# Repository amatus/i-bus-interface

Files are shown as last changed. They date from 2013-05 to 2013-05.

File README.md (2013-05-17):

i-bus-interface
===============

This project consists of a Bluetooth adapter that is connected
to the BMW I-Bus and an Android app that talks to the I-Bus
using the adapter.

The main goal of this project is to use the up and down buttons on
the BMW E46 steering wheel to send previous track and next track
commands to the music player on an Android device.

Cadsoft Eagle v6 files for the adapter are in the hardware directory
and Android software is in the android directory.

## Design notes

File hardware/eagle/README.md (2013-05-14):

I-Bus Adapter board
==================

The I-Bus Adapter board is designed to adapt the I-Bus signals to
TTL serial at 9600 baud 8E1. The serial pinout is compatible with
the Virtuabotix [BT2S] Bluetooth Serial Slave device.

I stuffed this board, the BT2S, and the board from a cheap USB phone
car charger into a small project box and connected it to the 3-pin
plug formerly connected to the Sirius satellite radio module in the
trunk of my BMW.

I-Bus Adapter with Power Supply
===============================

This is the same ciruit with the addition of a power supply based on
the MC34063 switching regulator.

Configuring the BT2S
====================

The bluetooth module on the BT2S seems to be a Guangzhou HC
Information Technology Co. [HC-06]. The full command set can be
found in the linked PDF. The module defaults to 9600 8N1 and in order
to change this to 8E1 AT-commands need to be sent to it over the serial
interface. I used an FT232R breakout board and minicom to communicate
with the module. The commands are sent without any pauses between bytes
and are terminated with a pause. They are *not* terminated with a carriage
return or line feed. The easiest way to achieve this is to type the command
out and copy it to the clipboard without a terminating newline, then paste
it into your terminal program. The commands are also not echoed, only the
response will appear in the terminal. The command for changing the parity
to even is `AT+PE`. This does not change the parity for the command
interface, only bluetooth passthrough, so the terminal parity should be left
at none.

Other useful commands:
* `AT+NAMExxxx` will change the name of the device for bluethooth
  discovery to xxxx.
* `AT+PIN0000` will change the pairing code to 0000 (must be 4 digits).
* `AT+PN` will set the parity back to none.

  [bt2s]: https://www.virtuabotix.com/?page_id=3117&productid=609224531705
  [hc-06]: http://www.mcu-turkey.com/wp-content/uploads/2013/01/HC-Serial-Bluetooth-Products-201104.pdf

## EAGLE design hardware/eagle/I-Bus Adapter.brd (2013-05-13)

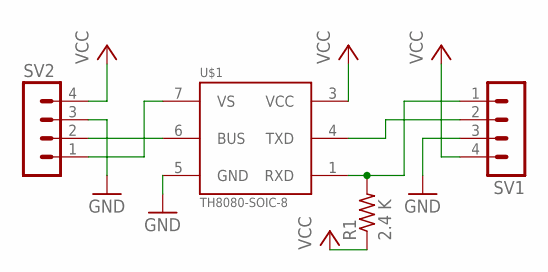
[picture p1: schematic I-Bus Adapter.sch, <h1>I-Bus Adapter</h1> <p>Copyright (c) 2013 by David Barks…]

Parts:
R1: 2.4 K; R1206
SV1, SV2: MA04-1
U$1: TH8080-SOIC-8; SO-8

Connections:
GND: SV1.3, SV2.3, U$1.5 (GND)
unnamed: R1.2, SV1.1, U$1.1 (RXD)
unnamed: SV1.2, U$1.4 (TXD)
unnamed: SV2.2, U$1.6 (BUS)
unnamed: SV2.1, U$1.7 (VS)
VCC: R1.1, SV1.4, SV2.4, U$1.3 (VCC)

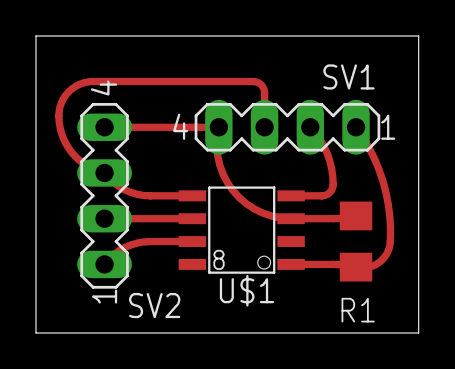
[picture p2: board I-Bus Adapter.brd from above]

Board: 2 copper layers, 21.3 x 16.5 mm, 4 parts (0 on the bottom side), 6 nets.

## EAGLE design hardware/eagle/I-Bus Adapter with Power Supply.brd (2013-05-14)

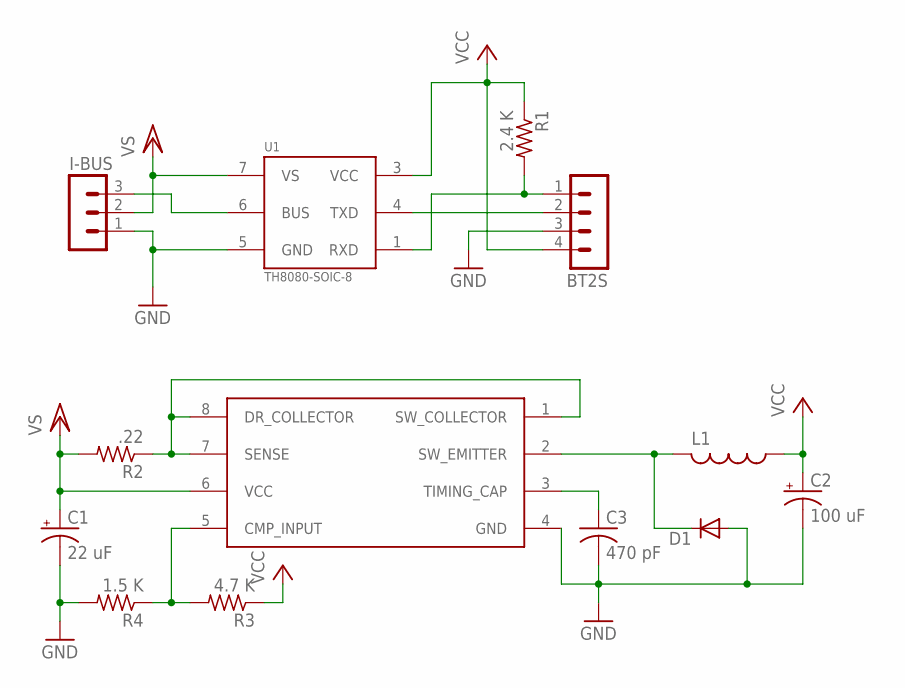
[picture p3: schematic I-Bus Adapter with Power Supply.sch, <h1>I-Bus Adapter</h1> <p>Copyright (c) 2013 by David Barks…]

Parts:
BT2S: MA04-1
C1: 22 uF; E1,8-4
C2: 100 uF; E1,8-4
C3: 470 pF; C0603K
D1: DIODE-D-2.5; D-2.5
I-BUS: MA03-1
L1: L-US0207/2V; 0207/2V
R1: 2.4 K; R1206
R2: .22; R1206
R3: 4.7 K; R2012
R4: 1.5 K; R2012
U1: TH8080-SOIC-8; SO-8
U2: MC34063-SOIC-8; SO-8

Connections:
GND: BT2S.3, C1.-, C2.-, C3.2, D1.A, I-BUS.1, R4.2, U1.5 (GND), U2.4 (GND)
unnamed: BT2S.1, R1.2, U1.1 (RXD)
unnamed: BT2S.2, U1.4 (TXD)
unnamed: R2.1, U2.1 (SW_COLLECTOR), U2.7 (SENSE), U2.8 (DR_COLLECTOR)
unnamed: I-BUS.3, U1.6 (BUS)
unnamed: D1.C, L1.2, U2.2 (SW_EMITTER)
unnamed: R3.2, R4.1, U2.5 (CMP_INPUT)
unnamed: C3.1, U2.3 (TIMING_CAP)
VCC: BT2S.4, C2.+, L1.1, R1.1, R3.1, U1.3 (VCC)
VCC/2: C1.+, I-BUS.2, R2.2, U1.7 (VS), U2.6 (VCC)

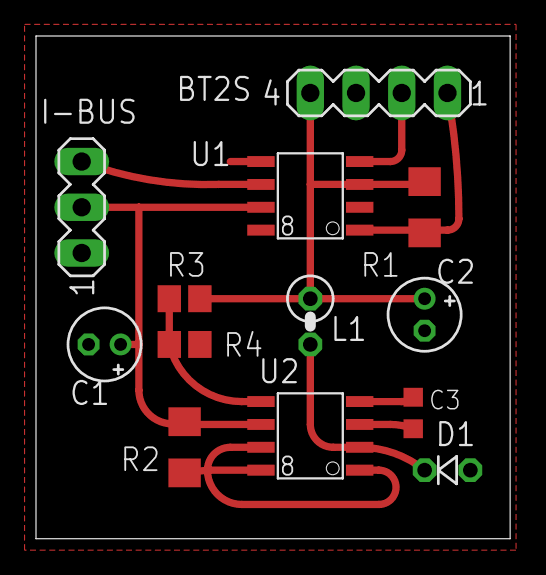
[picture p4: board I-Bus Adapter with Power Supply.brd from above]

Board: 2 copper layers, 26.3 x 27.9 mm, 13 parts (0 on the bottom side), 10 nets.

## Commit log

2013-05-12 I-Bus adapter board design.
    [IBUS_adapter.brd, IBUS_adapter.sch]
2013-05-13 Added CC BY-SA 3.0 license to hardware designs.
    [IBUS_adapter.brd, IBUS_adapter.sch]
2013-05-14 New design with power supply.
    I added a power supply and updated the readme.
    [I-Bus Adapter with Power Supply.brd, I-Bus Adapter with Power Supply.sch, I-Bus Adapter.brd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]
2013-05-23 Added steering wheel button events.
2014-02-17 New design based on the TI CC2541
    [I-Bus Adapter with Power Supply.brd, I-Bus Adapter with Power Supply.sch, I-Bus Adapter.brd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]
2014-02-17 Rules check found missing NCs
    [i-bus bluetooth soc.sch]
2014-02-20 New version using the MCP2025
    [i-bus bluetooth soc.sch]
2014-02-21 Component placement, fixed some modules
    [i-bus bluetooth soc.brd, i-bus bluetooth soc.sch]
2014-02-22 Changed power supply caps.
    [i-bus bluetooth soc.sch]
2014-02-22 Added .gitignore
    [i-bus bluetooth soc.brd]
2014-02-23 Changed the LEDs to active-low
    [i-bus bluetooth soc.sch]
2014-02-23 Some work on layout, upgraded kicad
    [i-bus bluetooth soc.brd]
2014-02-23 Initial layout finished
    [i-bus bluetooth soc.brd]
2014-02-23 Embiggened power and RF traces
    [i-bus bluetooth soc.brd]
2014-02-23 Connect thermal pad to ground
    [i-bus bluetooth soc.brd, i-bus bluetooth soc.sch]
2014-02-23 RF review and reconnected debug pins
    [i-bus bluetooth soc.brd]
2014-02-23 RF review, better placement
    [i-bus bluetooth soc.brd]
2014-02-23 Placed references and values
    [i-bus bluetooth soc.brd]
2014-02-23 Fixed LEDs
    [i-bus bluetooth soc.brd]
2014-02-23 Fix connectivity
    [i-bus bluetooth soc.brd]
2014-02-23 Generated gerbers, not sure what changed
    [i-bus bluetooth soc.brd]
2014-02-23 Tweaking fill clearance
    Why do fills not avoid masked areas?
    [i-bus bluetooth soc.brd]
2014-02-23 Labeled headers
    [i-bus bluetooth soc.brd]
2014-03-30 Fix C1 silkscreen.
    [i-bus bluetooth soc.brd]

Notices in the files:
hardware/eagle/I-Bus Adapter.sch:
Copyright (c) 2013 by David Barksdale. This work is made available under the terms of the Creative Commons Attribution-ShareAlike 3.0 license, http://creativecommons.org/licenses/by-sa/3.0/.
